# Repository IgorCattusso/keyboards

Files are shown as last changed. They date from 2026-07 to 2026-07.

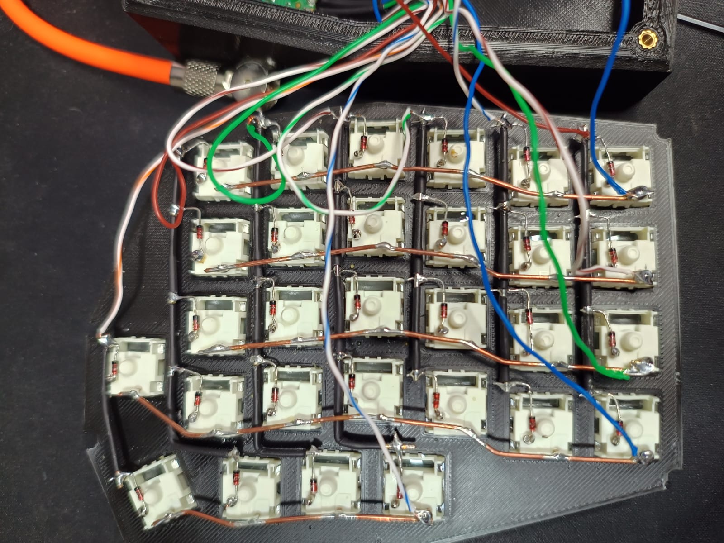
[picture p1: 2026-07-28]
Nexus-58-Mk-I/photos/Left Side - Switches Wiring.jpeg

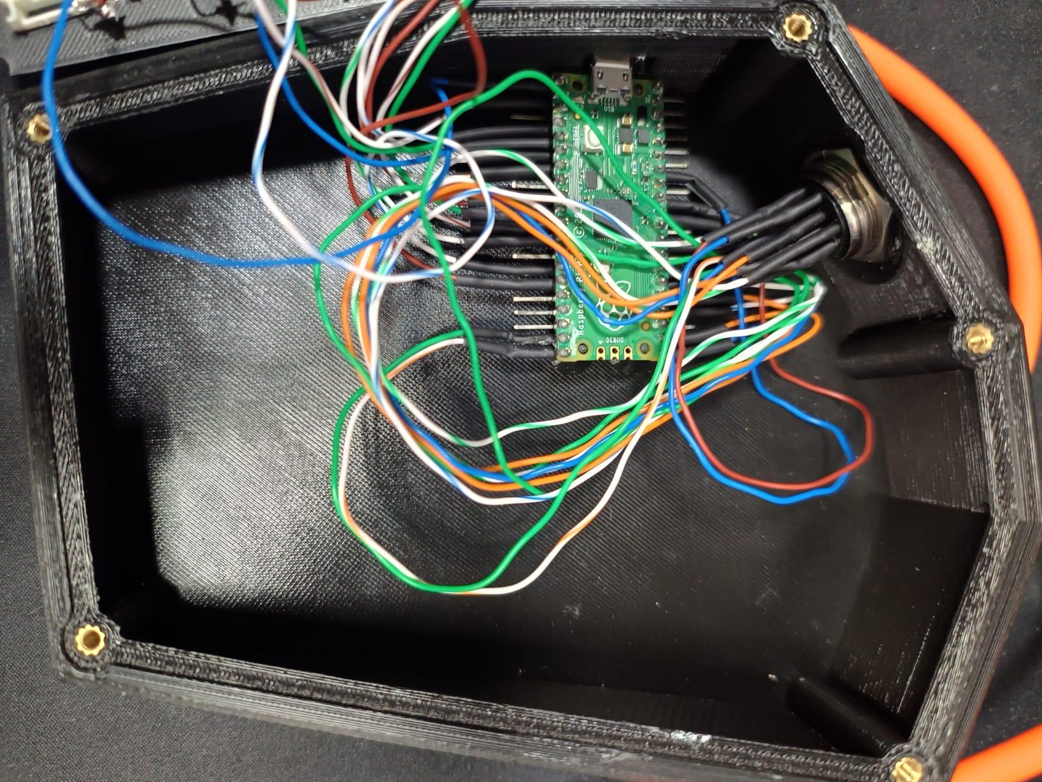
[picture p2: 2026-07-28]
Nexus-58-Mk-I/photos/Left Side - MCU Wiring.jpeg

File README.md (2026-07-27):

# Keyboard Projects

This repository contains a collection of my custom mechanical keyboard projects. All related projects are organized here in their own directories.

Each project includes its own documentation, CAD files, firmware, wiring information, and any additional resources required to reproduce or modify the design.

---

## Projects

| Project | Description | Status |
| --- | --- | --- |
| **Nexus-58 Mk.I**  | Hand-wired 58-key split keyboard powered by the RP2040. | Done |
| **Nexus-58 Mk.II** | Hand-wired 58-key split keyboard powered by the RP2040. | In Progress |

---

## Repository Structure

```text
/
├── Nexus-58-Mk-I/
│   ├── README.md
│   ├── software/
│   ├── stls/
│   ├── photos/
└── README.md
```

---

## License


The work under this repository is licensed under a Creative Commons Attribution-NonCommercial-ShareAlike 4.0 International License.

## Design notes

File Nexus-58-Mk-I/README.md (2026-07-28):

# Nexus-58 Mk.I

A fully hand-wired 58-key slightly tented split mechanical keyboard designed around the Raspberry Pi RP2040 with direct connection on both halves.
Connection type inspired by the [ScottoSplit](https://scottokeebs.com/blogs/keyboards/scottosplit).

Nexus-58 Mk.I is the first iteration of my Nexus series. My goal with this project was to create a practical, repairable, and completely custom split keyboard using readily available components and a fully 3D-printed case.

## Repository Contents

```text
Nexus-58-Mk-I/
├── photos/         # 3D printable models
├── software/       # Firmware source
├── stls/           # Photos and renders
└── README.md
```

## Features

- 58-key split layout
- Hand-wired switch matrix (no PCB)
- Raspberry Pi Pico (RP2040)
- 3D-printed case
- GX20 Aviation connector with 12 Pins
- Mechanical key switches (Gateron Blue)
- Open-source hardware and firmware

## Design Philosophy

Instead of relying on a custom PCB, Nexus-58 Mk.I uses a hand-wired matrix. This makes the keyboard easier to modify, repair, and experiment with while keeping manufacturing accessible to anyone with basic soldering tools and a 3D printer.

The circular interconnect cable provides a direct connection between both halves while carrying the required signals through a single cable. This connector was chosen to reduce the cost by eliminating the need of having an MCU in each side. Also, this type of connector can be disconnected any time without worries.

A GX20 Aviation connector with 12 Pins was used on this project, but any type of connector can be used, as long as it has 12 pins to carry the signal from all 7 columns and 5 rows from the right side to the left side that has the MCU. A second MCU can be used on the right side with a P2 or USB cabe interconnecting both sides, but that would elevate the cost significantly (in my country, at least).

## Firmware and software
This project uses [KMK Firmware](https://github.com/KMKfw/kmk_firmware), and requires [CircuitPython](https://circuitpython.org/) installed on the MCU.

After installing the firmware, simply drop the `Nexus-58-Mk-I/software/code.py` file on the root directory of the MCU.

## Components

Most of the components were bought in Brazil, where I live:
- Raspberry Pi Pico (RP2040): [RoboCore](https://www.robocore.net/placa-raspberry-pi/raspberry-pi-pico/)
- Pins for the Pi Pico: [RoboCore](https://www.robocore.net/conector/barra-de-40-pinos-macho-90-5-unidades/)
- Diodes 1n4148: [Mercado Livre](https://www.mercadolivre.com.br/diodo-de-sinal-1n4148-kit-200-pecas/p/MLB2072206267)
- Brass screw inserts: [Mercado Livre](https://www.mercadolivre.com.br/kit-50-inserto-metalico-de-rosca-m3-impressoes-3d/up/MLBU605703878)
- Black M3 screws: [Parafuso Fácil](https://www.parafusofacil.com.br/parafuso-allen/parafuso-allen-chato/din-7991-parafuso-allen-chato-ma-3-x-6-aco-liga-classe-10-9-enegrecido-de-tempera-1/)
- GX20 Aviation connector with 12 Pins: [Elecbee](https://www.elecbee.com/en/product-detail/10sets-gx20-aviation-connector-male-and-female-one-pair-12pin-straightpanel-mount-solder-type-connector_5743)
- Mechanical key switches (Gateron Blue): [AliExpress](https://pt.aliexpress.com/item/1005005550328893.html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)
- USB cable: [Mercado Livre](https://produto.mercadolivre.com.br/MLB-5541283014-cabo-usb-carregador-celular-tipo-c-reforcado-5a-gamer-120w-_JM)
- Wires: All wires that connect both halves came from old Cat6 ethernet cables. The wires that connect rows and columns came from old coaxial cables.

## Future Revisions

The Mk.I establishes the foundation for future Nexus keyboards. Later revisions may include improved ergonomics, wireless connectivity, or additional features while maintaining compatibility where practical.

## License

See the repository's license file for licensing information.

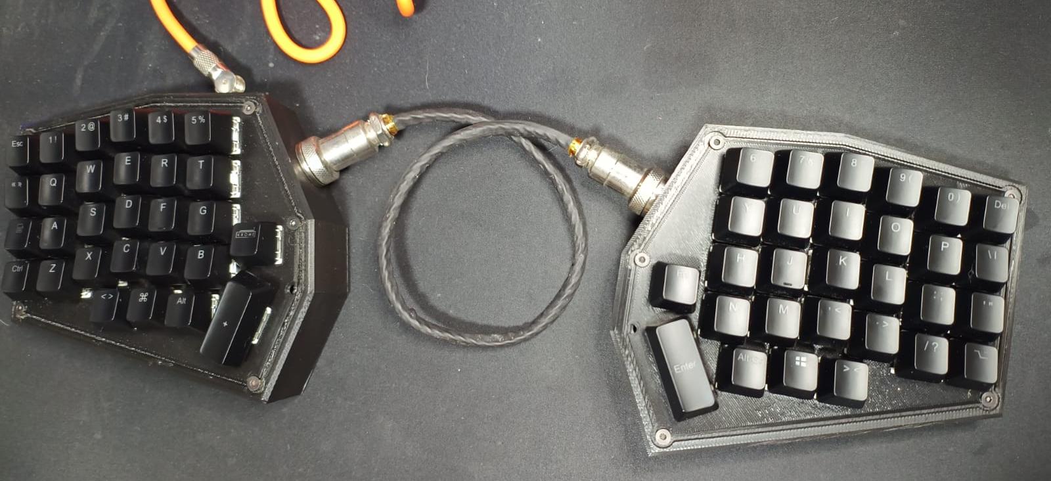
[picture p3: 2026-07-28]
Nexus-58-Mk-I/photos/Full View.jpeg

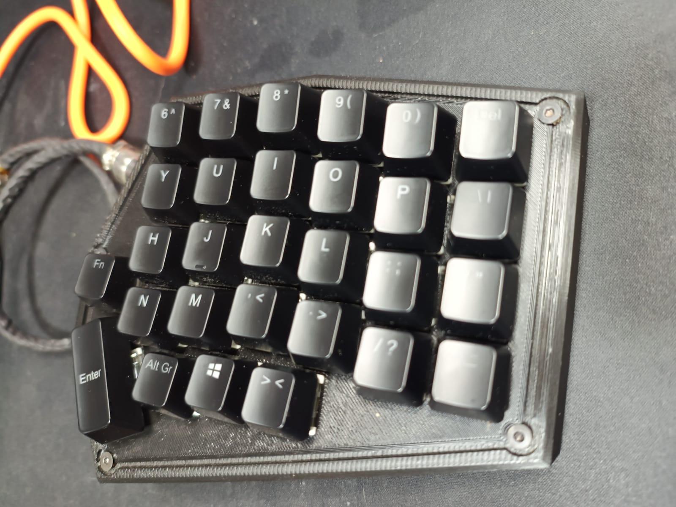
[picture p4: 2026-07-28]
Nexus-58-Mk-I/photos/Right Side - Closed View.jpeg

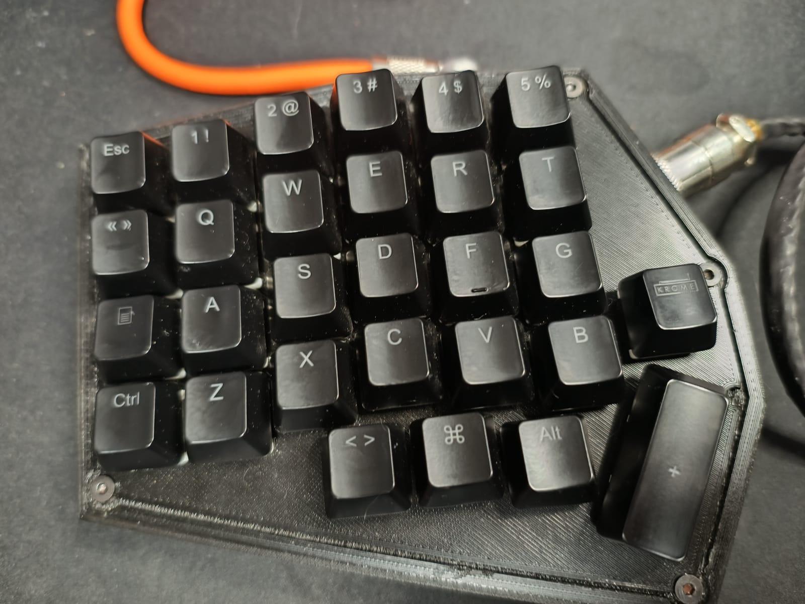
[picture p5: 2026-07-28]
Nexus-58-Mk-I/photos/Left Side - Closed case.jpeg

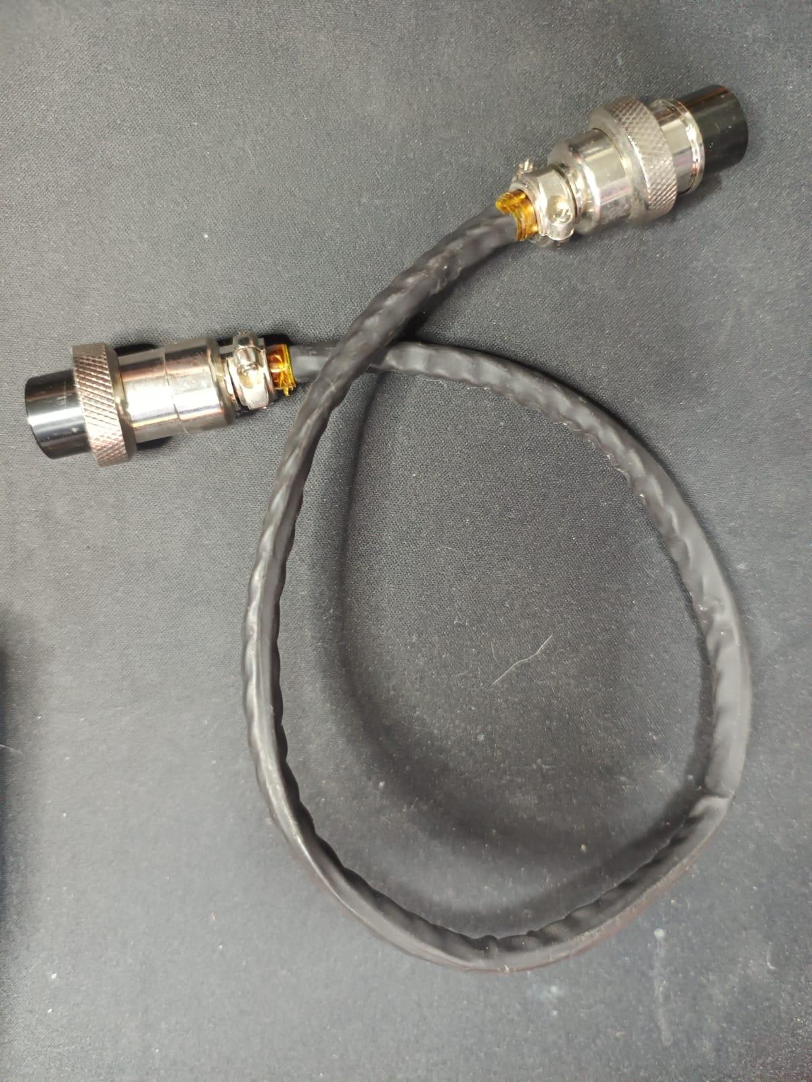
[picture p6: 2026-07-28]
Nexus-58-Mk-I/photos/Connector.jpeg

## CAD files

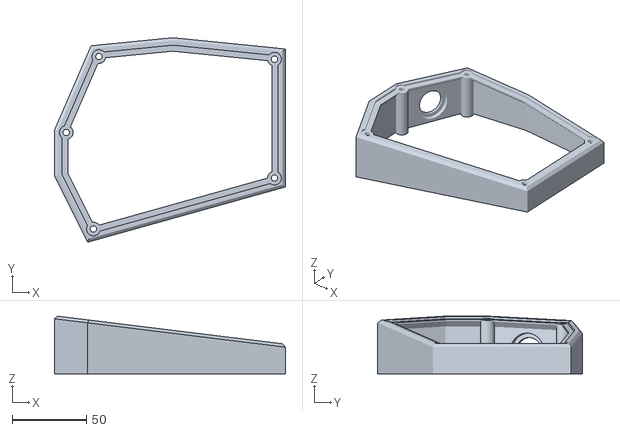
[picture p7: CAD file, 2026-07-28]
Nexus-58-Mk-I/stls/Right Case.stl
155.8 x 137.9 x 38.9

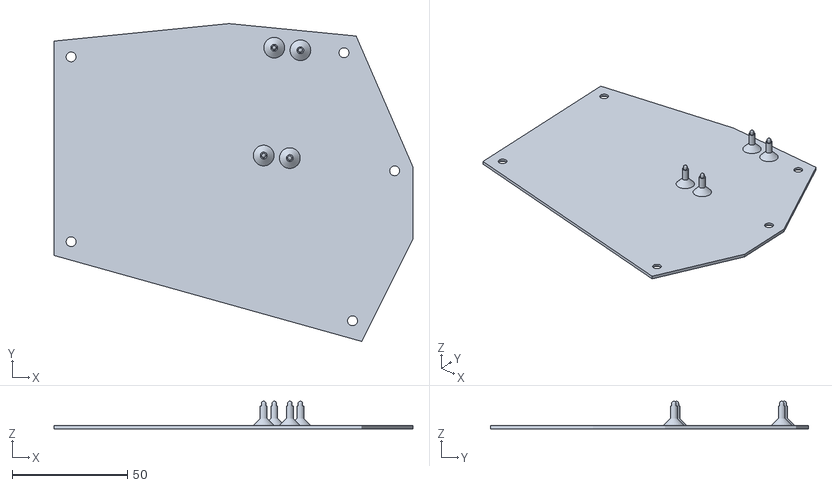
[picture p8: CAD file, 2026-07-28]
Nexus-58-Mk-I/stls/Left bottom plate.stl
155.8 x 137.9 x 12.0

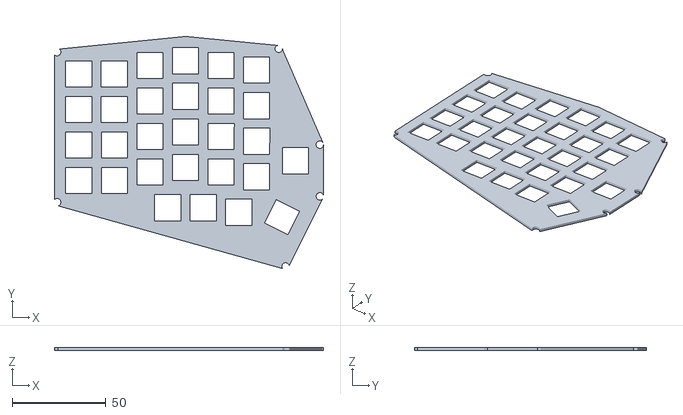
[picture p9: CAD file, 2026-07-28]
Nexus-58-Mk-I/stls/Left top plate.stl
143.8 x 124.1 x 1.50

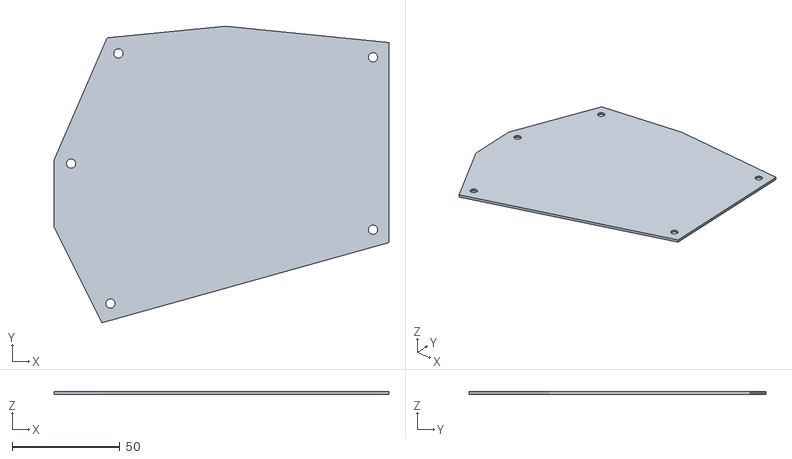
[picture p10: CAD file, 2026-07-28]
Nexus-58-Mk-I/stls/Right bottom plate.stl
155.8 x 137.9 x 1.50

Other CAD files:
Nexus-58-Mk-I/stls/Left Case.stl
Nexus-58-Mk-I/stls/Right top plate.stl

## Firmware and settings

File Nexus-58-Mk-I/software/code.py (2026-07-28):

import board

from kmk.kmk_keyboard import KMKKeyboard
from kmk.keys import KC
from kmk.scanners import DiodeOrientation
from kmk.modules.layers import Layers


keyboard = KMKKeyboard()

keyboard.row_pins = (
    # LEFT SIDE
    board.GP0, board.GP1, board.GP2, board.GP3, board.GP4,

    # RIGHT SIDE
    board.GP28, board.GP27, board.GP26, board.GP22, board.GP21,
    # pin 1   # pin 2       # pin 3     # pin 4     # pin 5
)

keyboard.col_pins = (
    # LEFT SIDE
    board.GP11, board.GP10, board.GP9, board.GP8, board.GP7, board.GP6, board.GP5,

    # RIGHT SIDE
    board.GP20, board.GP19, board.GP18, board.GP17, board.GP16, board.GP15, board.GP14,
    # pin 6   # pin 7       # pin 8     # pin 9     # pin 10    # pin 11    # pin 12
)

keyboard.diode_orientation = DiodeOrientation.ROW2COL

keyboard.modules.append(Layers())

TRANS = KC.TRNS # Creates a transparent Key. Transparent Keys are pressed through the upper layer to the lower layer.
LAYER = KC.MO(1) # Momentarily activate LAYER 1 until released

keyboard.keymap = [
    [   # LAYER 0 - Base Layer
        # LEFT SIDE                                                                         # RIGHT SIDE (THIS TOP PART DOES NOTHING)
        KC.GRAVE,     KC.N1,     KC.N2,    KC.N3,      KC.N4,      KC.N5,      KC.NO,       KC.NO,       KC.NO,      KC.NO,      KC.NO,       KC.NO,     KC.NO,        KC.NO,
        KC.TAB,       KC.Q,      KC.W,     KC.E,       KC.R,       KC.T,       KC.NO,       KC.NO,       KC.NO,      KC.NO,      KC.NO,       KC.NO,     KC.NO,        KC.NO,
        KC.LSHIFT,    KC.A,      KC.S,     KC.D,       KC.F,       KC.G,       KC.NO,       KC.NO,       KC.NO,      KC.NO,      KC.NO,       KC.NO,     KC.NO,        KC.NO,
        KC.LCTRL,     KC.Z,      KC.X,     KC.C,       KC.V,       KC.B,       LAYER,       KC.NO,       KC.NO,      KC.NO,      KC.NO,       KC.NO,     KC.NO,        KC.NO,
        KC.NO,        KC.NO,     KC.NO,    KC.HOME,    KC.LGUI,    KC.LALT,    KC.SPACE,    KC.NO,       KC.NO,      KC.NO,      KC.NO,       KC.NO,     KC.NO,        KC.NO,
        # LEFT SIDE (THIS BOTTOM PART DOES NOTHING)                                         # RIGHT SIDE
        KC.NO,        KC.NO,     KC.NO,    KC.NO,      KC.NO,      KC.NO,      KC.NO,       KC.NO,       KC.N6,      KC.N7,      KC.N8,       KC.N9,     KC.N0,        KC.DEL,
        KC.NO,        KC.NO,     KC.NO,    KC.NO,      KC.NO,      KC.NO,      KC.NO,       KC.NO,       KC.Y,       KC.U,       KC.I,        KC.O,      KC.P,         KC.BSLASH,
        KC.NO,        KC.NO,     KC.NO,    KC.NO,      KC.NO,      KC.NO,      KC.NO,       KC.NO,       KC.H,       KC.J,       KC.K,        KC.L,      KC.SCOLON,    KC.QUOTE,
        KC.NO,        KC.NO,     KC.NO,    KC.NO,      KC.NO,      KC.NO,      KC.NO,       LAYER,       KC.N,       KC.M,       KC.COMMA,    KC.DOT,    KC.SLASH,     KC.PSCREEN,
        KC.NO,        KC.NO,     KC.NO,    KC.NO,      KC.NO,      KC.NO,      KC.NO,       KC.BSPACE,   KC.RALT,    KC.LGUI,    KC.END,      KC.NO,     KC.NO,        KC.NO,
    ],
    [   # LAYER 1 - Special Characters and secondary actions
        # LEFT SIDE BEGINS HERE                                                             # RIGHT SIDE (THIS TOP PART DOES NOTHING)
        KC.ESC,    KC.F1,      KC.F2,      KC.F3,       KC.F4,    KC.F5,          KC.NO,    KC.NO,       KC.NO,          KC.NO,    KC.NO,     KC.NO,       KC.NO,       KC.NO,
        TRANS,     KC.NO,      KC.UP,      KC.NO,       KC.NO,    KC.LBRACKET,    KC.NO,    KC.NO,       KC.NO,          KC.NO,    KC.NO,     KC.NO,       KC.NO,       KC.NO,
        TRANS,     KC.LEFT,    KC.DOWN,    KC.RIGHT,    KC.NO,    KC.NO,          KC.NO,    KC.NO,       KC.NO,          KC.NO,    KC.NO,     KC.NO,       KC.NO,       KC.NO,
        TRANS,     KC.NO,      KC.CAPS,    KC.NO,       KC.NO,    KC.NO,          KC.NO,    KC.NO,       KC.NO,          KC.NO,    KC.NO,     KC.NO,       KC.NO,       KC.NO,
        KC.NO,     KC.NO,      KC.NO,      TRANS,       TRANS,    TRANS,          TRANS,    KC.NO,       KC.NO,          KC.NO,    KC.NO,     KC.NO,       KC.NO,       KC.NO,
        # LEFT SIDE (THIS BOTTOM PART DOES NOTHING)                                         # RIGHT SIDE
        KC.NO,     KC.NO,      KC.NO,      KC.NO,       KC.NO,    KC.NO,          KC.NO,    KC.NO,       KC.F6,          KC.F7,    KC.F8,     KC.F9,       KC.F10,      KC.F11,
        KC.NO,     KC.NO,      KC.NO,      KC.NO,       KC.NO,    KC.NO,          KC.NO,    KC.NO,       KC.RBRACKET,    KC.NO,    KC.NO,     KC.MINUS,    KC.EQUAL,    KC.F12,
        KC.NO,     KC.NO,      KC.NO,      KC.NO,       KC.NO,    KC.NO,          KC.NO,    KC.NO,       KC.NO,          KC.NO,    KC.NO,     KC.NO,       KC.NO,       KC.NO,
        KC.NO,     KC.NO,      KC.NO,      KC.NO,       KC.NO,    KC.NO,          KC.NO,    KC.NO,       KC.NO,          KC.NO,    KC.NO,     KC.NO,       KC.NO,       KC.NO,
        KC.NO,     KC.NO,      KC.NO,      KC.NO,       KC.NO,    KC.NO,          KC.NO,    KC.ENTER,    TRANS,          TRANS,    TRANS,     KC.NO,       KC.NO,       KC.NO,
    ]
]

keyboard.debug_enabled = True

if __name__ == '__main__':
    keyboard.go()
